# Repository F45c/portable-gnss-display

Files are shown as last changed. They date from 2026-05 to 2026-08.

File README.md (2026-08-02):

# Portable GNSS / GPS Display
### What it is
The Display shows a satellite map of your nearby surroundings with an indicator in the center of the device's location. It not only uses GPS satellites but also the european Galileo, BeiDou and some others.
With the UART connections and USB connectors, you can read the position with a phone or a computer.

### How it works
It uses the ublox neo m9n chip with an active antenna and an Esp32-C3 that extracts the position, calculates the tiles to draw on the screen and draws them together with a position mark on the display.
The tiles are stored on sd card slot in the tft display and are pre-downloaded on set sd card for a small area around my home town.

### Finished Module
I finished the PCB assembly. It was difficult to solder the tiny components and especially the SMD parts. Thankfully, with the help of solder flux and a heat gun, I was able to solder everything on the pcb.
The most annoying component was the USB-C connector because the pins are so tiny and would always bridge multiple together.

I downloaded a few tiles where I live and put them on an sd card. I had to censor the map mostly so I don't leak my address. The example image is below.

It's a very nice device but after all, I still use my phone more often than this.

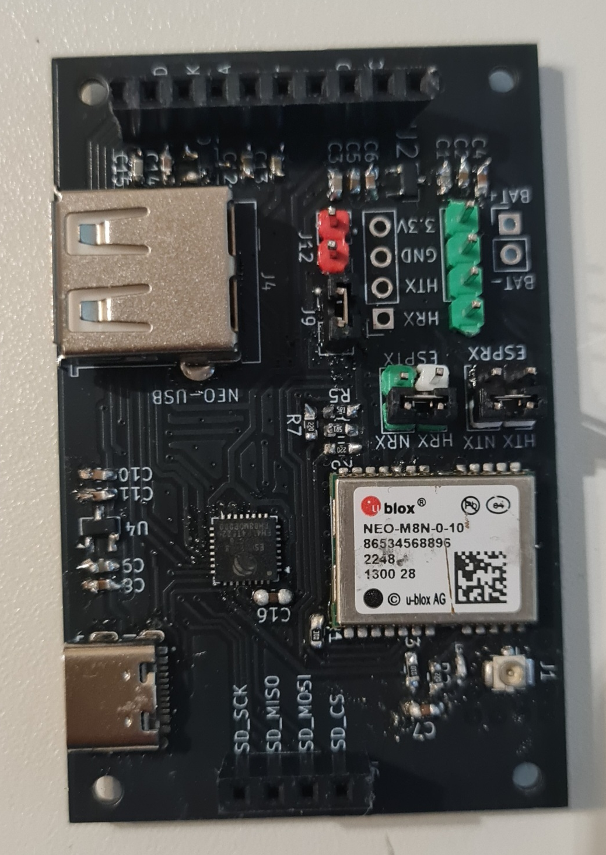
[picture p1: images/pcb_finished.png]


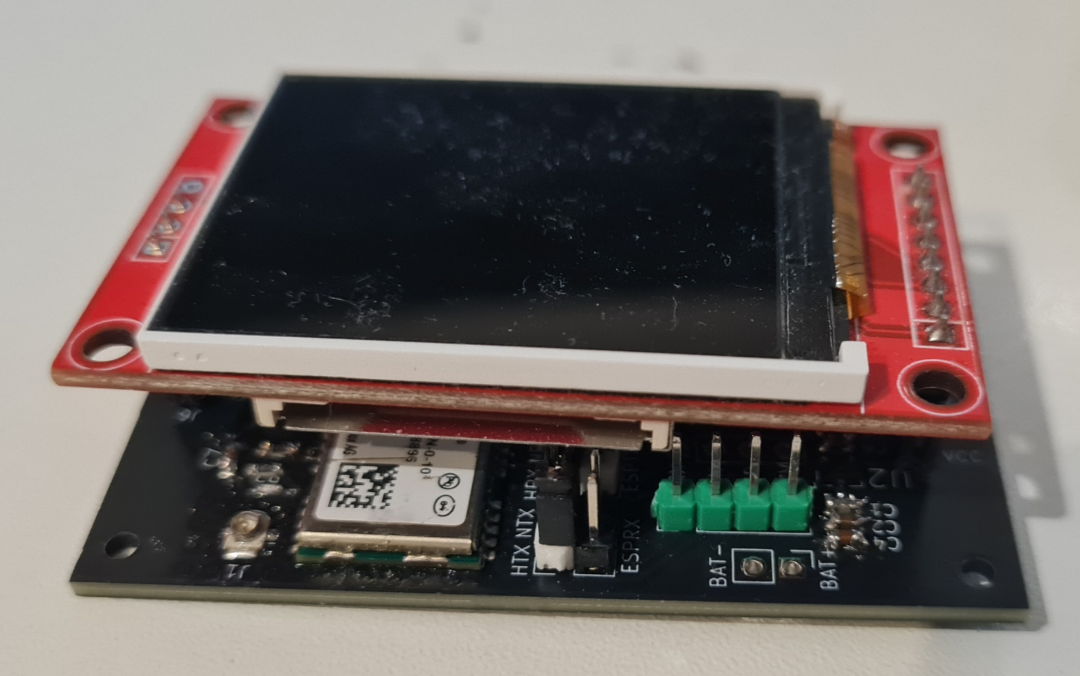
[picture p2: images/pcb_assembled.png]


(Redacted display because it shows my home location)

In the center, on the red + symbol is the gps position and on top is the N for north.

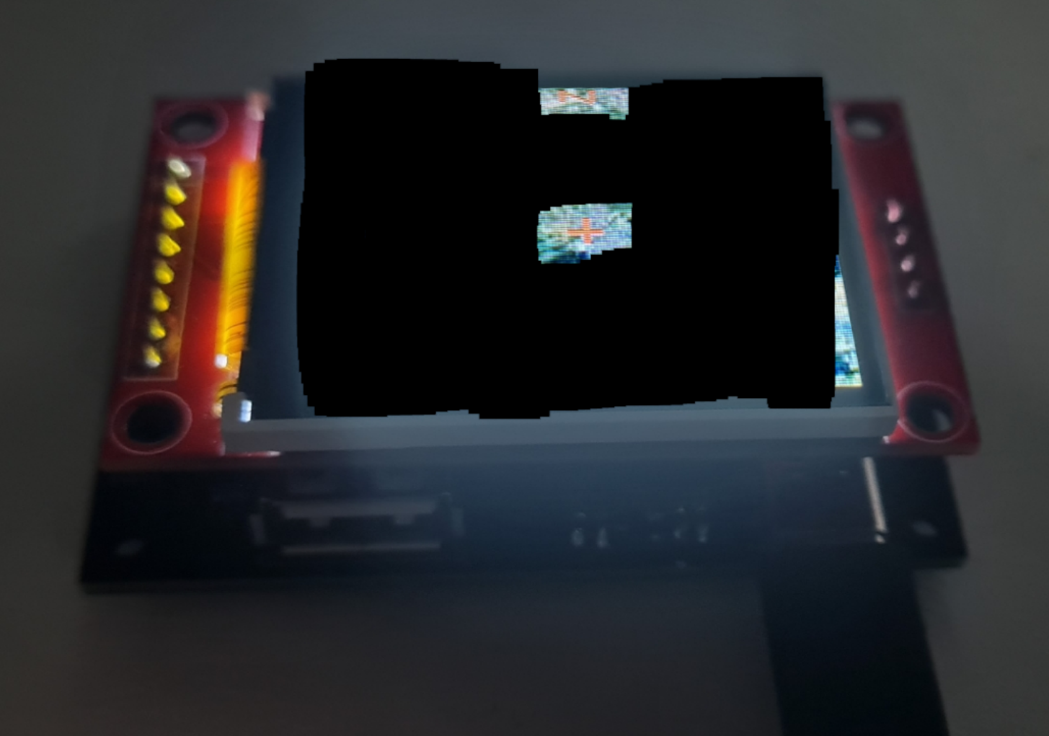
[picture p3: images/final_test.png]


#### Technical Details
> The Neo M9N can be directly connected via USB-A Connector to an external device
>
>The Esp32 and Neo communicate over UART with baud rate 9600
>
>The Esp32 communicates with the display and sd card over SPI
>
>
>With some jumper pins, you can configure which part of the PCB is powered with what source.
>
>The UART pin headers are for using an external uart connection to read the position or communicate with the Esp32.
>This can also be configured using jumper pins

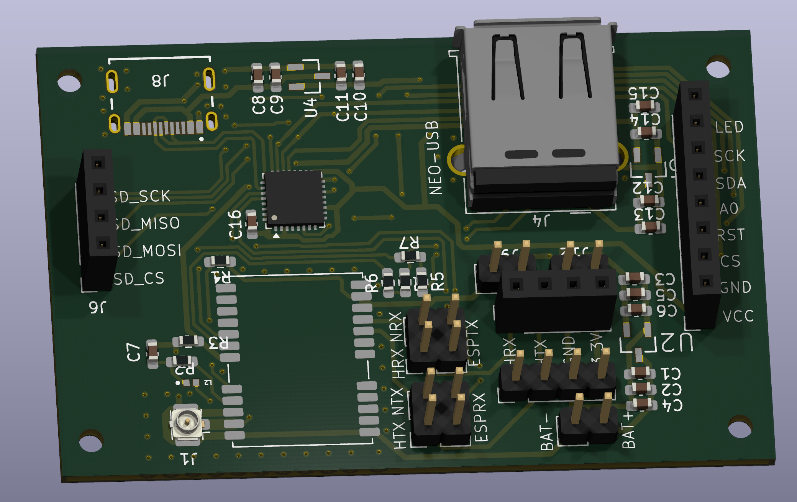
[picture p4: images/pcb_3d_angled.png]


#### Components
> uBlox Neo M9N -> GNSS Receiver
>
> Esp32-C3 -> processor
>
>  1.8 inch TFT Display with SD CARD -> Display
>
> Active Antenna -> better reception
>
> MCP170XT-3302E -> 3.3V Linear Voltage Regulator

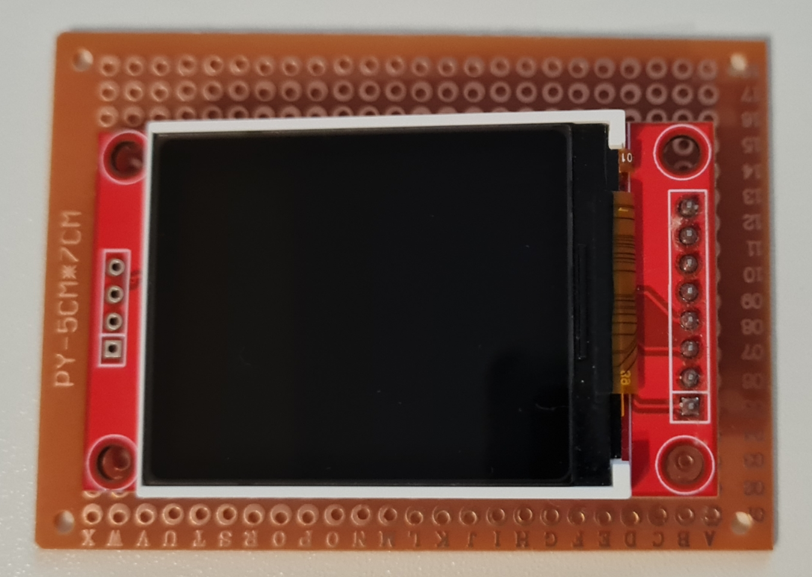
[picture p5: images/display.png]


### Why I made this
I wanted to have a device showing my exact location reliably because google maps sometimes doesn't show my location when my phone has bad cellular reception (even with good gps reception).

I also like satellite maps instead of normal street lines maps to better see what's around me and since the satellite images aren't up to date, you can see how the world changed.

It's kind of an extra gadget that doesn't require a phone to work and, as mentioned, runs reliably all the time, can't be hacked etc.

### Schematic

#### Some mentionable parts
> 27 Ω resistors (22+5.1) between D+/D- lines to Neo for full-speed driver
>
> lots of capacitors around LDOs for stable voltage
>
> important bias T at antenna input for active antennas
>
> Neo VDD_USB needs to be pulled down when not in use
>
> Jumper pin configuring happening on the left
>
> Three power source inputs to choose from (USB-A, USB-C, battery)

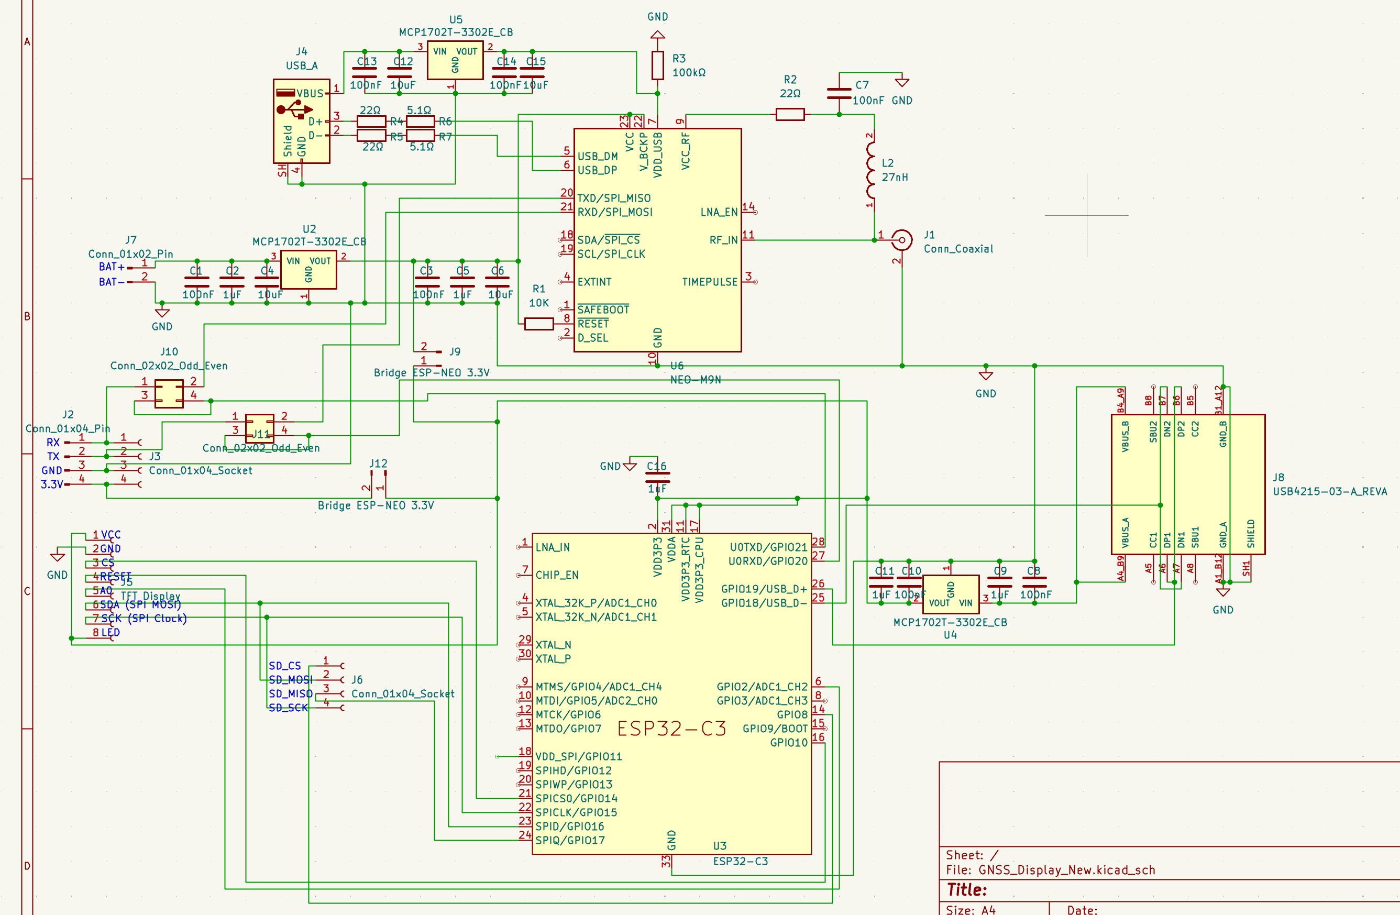
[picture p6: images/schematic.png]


### PCB Design
The first thing to mention is that the 1.8inch display has enough room and isn't blocked by any components. I made sure of that through the entire development process.

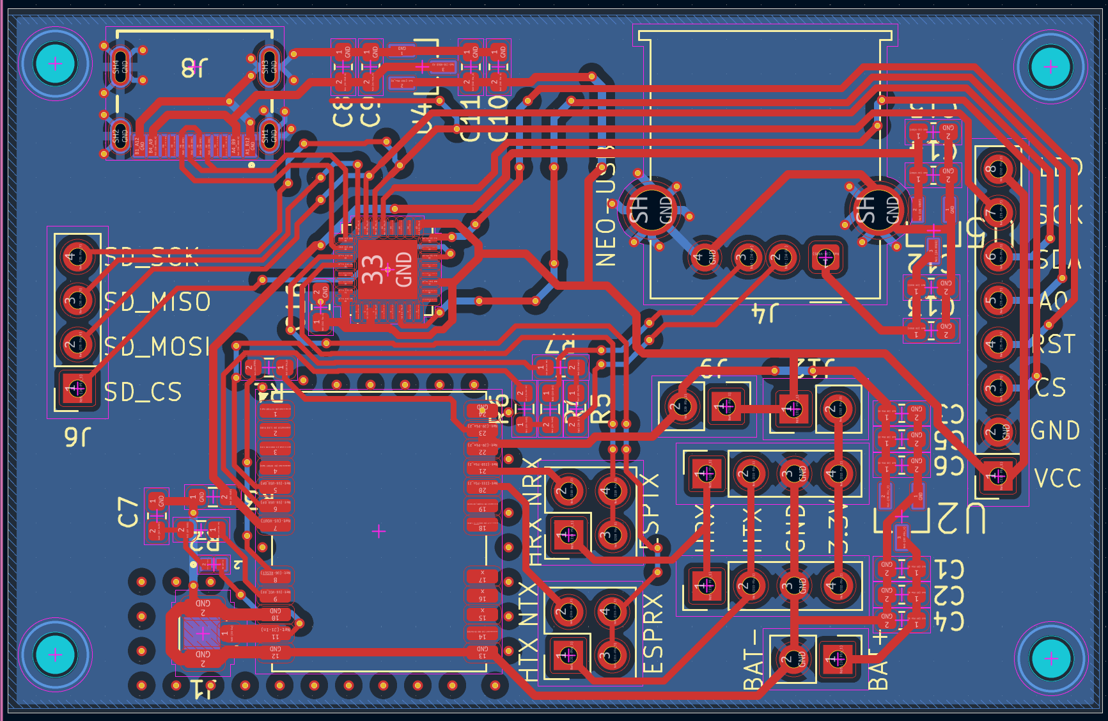
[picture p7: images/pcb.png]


#### Key Aspects of the Design
> minimum track width = 0.3mm, most power traces = 0.5mm
> lots of vias around the Neo and antenna connector shielding from interference
> four mounting holes when I want to screw it onto something
> tried to make it as small as possible
> track from antenna to Neo Pin has 50ohm impedance
> Ground Plane

When routing on the back layer (ground plane), I tried to make short cuts between the tracks so that the ground plane works better and the path of the current is as short as possible.

Here is an example of this where you can see the spacing between the different tracks on the ground plane (blue layer)

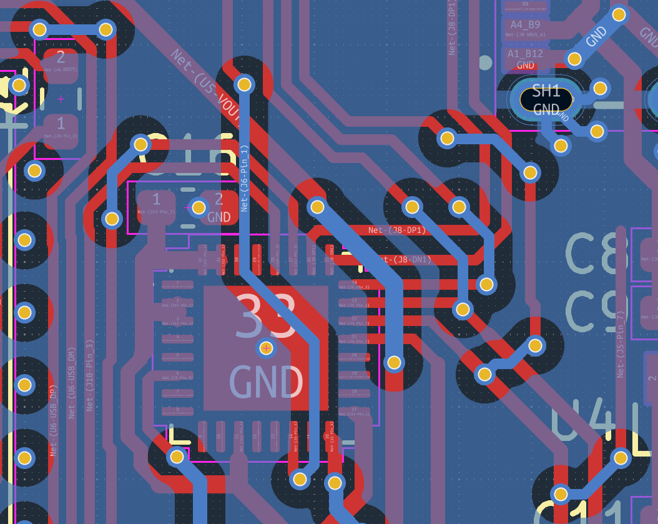
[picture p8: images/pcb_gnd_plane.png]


### BOM

| Name | Purpose | Quantity | Total Cost (USD) | Link | Distributor |
|---|---|---|---|---|---|
| PCB | PCB board | 1 | 5.50 | | JLCPCB |
| Display | 1.8 inch TFT display | 1 | 6.47 | [Link](https://www.amazon.com/Chiffonade-Display-Interface-128x160-Resolution/dp/B0FQJX2SJV/) | Amazon |
| Antenna | GPS Antenna | 1 | 7.99 | [Link](https://www.amazon.com/28dB-High-Active-Antenna-Built/dp/B0C3H6BKHC) | Amazon |
| PCBA | PCB Assembly Parts | 1 | 33.27 | | |

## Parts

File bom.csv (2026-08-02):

Name | Purpose | Quantity | Total Cost (USD) | Link | Distributor
PCB | PCB board | 1 | 5.5 |  | JLCPCB
Display | 1.8 inch TFT display | 1 | 6.47 | https://www.amazon.com/Chiffonade-Display-Interface-128x160-Resolution/dp/B0FQJX2SJV/ | Amazon
Antenna | GPS Antenna | 1 | 7.99 | https://www.amazon.com/28dB-High-Active-Antenna-Built/dp/B0C3H6BKHC | Amazon
PCBA | PCB Assembly Parts | 1 | 33.27

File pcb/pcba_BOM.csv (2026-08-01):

Reference | Qty | Value | DNP | Exclude from BOM | Exclude from Board | Footprint | Datasheet
C1,C3,C7,C8,C10,C13,C14 | 7 | 100nF |  |  |  | Capacitor_SMD:C_0603_1608Metric_Pad1.08x0.95mm_HandSolder
C2,C5,C9,C11,C16 | 5 | 1uF |  |  |  | Capacitor_SMD:C_0603_1608Metric_Pad1.08x0.95mm_HandSolder
C4,C6,C12,C15 | 4 | 10uF |  |  |  | Capacitor_SMD:C_0603_1608Metric_Pad1.08x0.95mm_HandSolder
J1 | 1 | Conn_Coaxial |  |  |  | Connector_Coaxial:U.FL_Hirose_U.FL-R-SMT-1_Vertical
J2 | 1 | Conn_01x04_Pin |  |  |  | Connector_PinHeader_2.54mm:PinHeader_1x04_P2.54mm_Vertical
J3,J6 | 2 | Conn_01x04_Socket |  |  |  | Connector_PinSocket_2.54mm:PinSocket_1x04_P2.54mm_Vertical
J4 | 1 | USB_A |  |  |  | Connector_USB:USB_A_Molex_67643_Horizontal
J5 | 1 | TFT Display |  |  |  | Connector_PinSocket_2.54mm:PinSocket_1x08_P2.54mm_Vertical
J7 | 1 | Conn_01x02_Pin |  |  |  | Connector_PinHeader_2.54mm:PinHeader_1x02_P2.54mm_Vertical
J8 | 1 | USB4215-03-A_REVA |  |  |  | USB4215-03-A_REVA:GCT_USB4215-03-A_REVA
J9,J12 | 2 | Bridge ESP-NEO 3.3V |  |  |  | Connector_PinHeader_2.54mm:PinHeader_1x02_P2.54mm_Vertical
J10,J11 | 2 | Conn_02x02_Odd_Even |  |  |  | Connector_PinHeader_2.54mm:PinHeader_2x02_P2.54mm_Vertical
L2 | 1 | 27nH |  |  |  | LQG15HS27NJ02D:INDC1005X55N
R1 | 1 | 10K |  |  |  | Resistor_SMD:R_0603_1608Metric_Pad0.98x0.95mm_HandSolder
R2,R4,R5 | 3 | 22Ω |  |  |  | Resistor_SMD:R_0603_1608Metric_Pad0.98x0.95mm_HandSolder
R3 | 1 | 100kΩ |  |  |  | Resistor_SMD:R_0603_1608Metric_Pad0.98x0.95mm_HandSolder
R6,R7 | 2 | 5.1Ω |  |  |  | Resistor_SMD:R_0603_1608Metric_Pad0.98x0.95mm_HandSolder
U2,U4,U5 | 3 | MCP1702T-3302E_CB |  |  |  | MCP1702T-3302E_CB:SOT95P255X145-3N
U3 | 1 | ESP32-C3 |  |  |  | Package_DFN_QFN:QFN-32-1EP_5x5mm_P0.5mm_EP3.45x3.45mm | https://www.espressif.com/sites/default/files/documentation/esp32-c3_datasheet_en.pdf
U6 | 1 | NEO-M9N |  |  |  | RF_GPS:ublox_NEO | https://www.u-blox.com/sites/default/files/NEO-M9N-00B_DataSheet_UBX-19014285.pdf

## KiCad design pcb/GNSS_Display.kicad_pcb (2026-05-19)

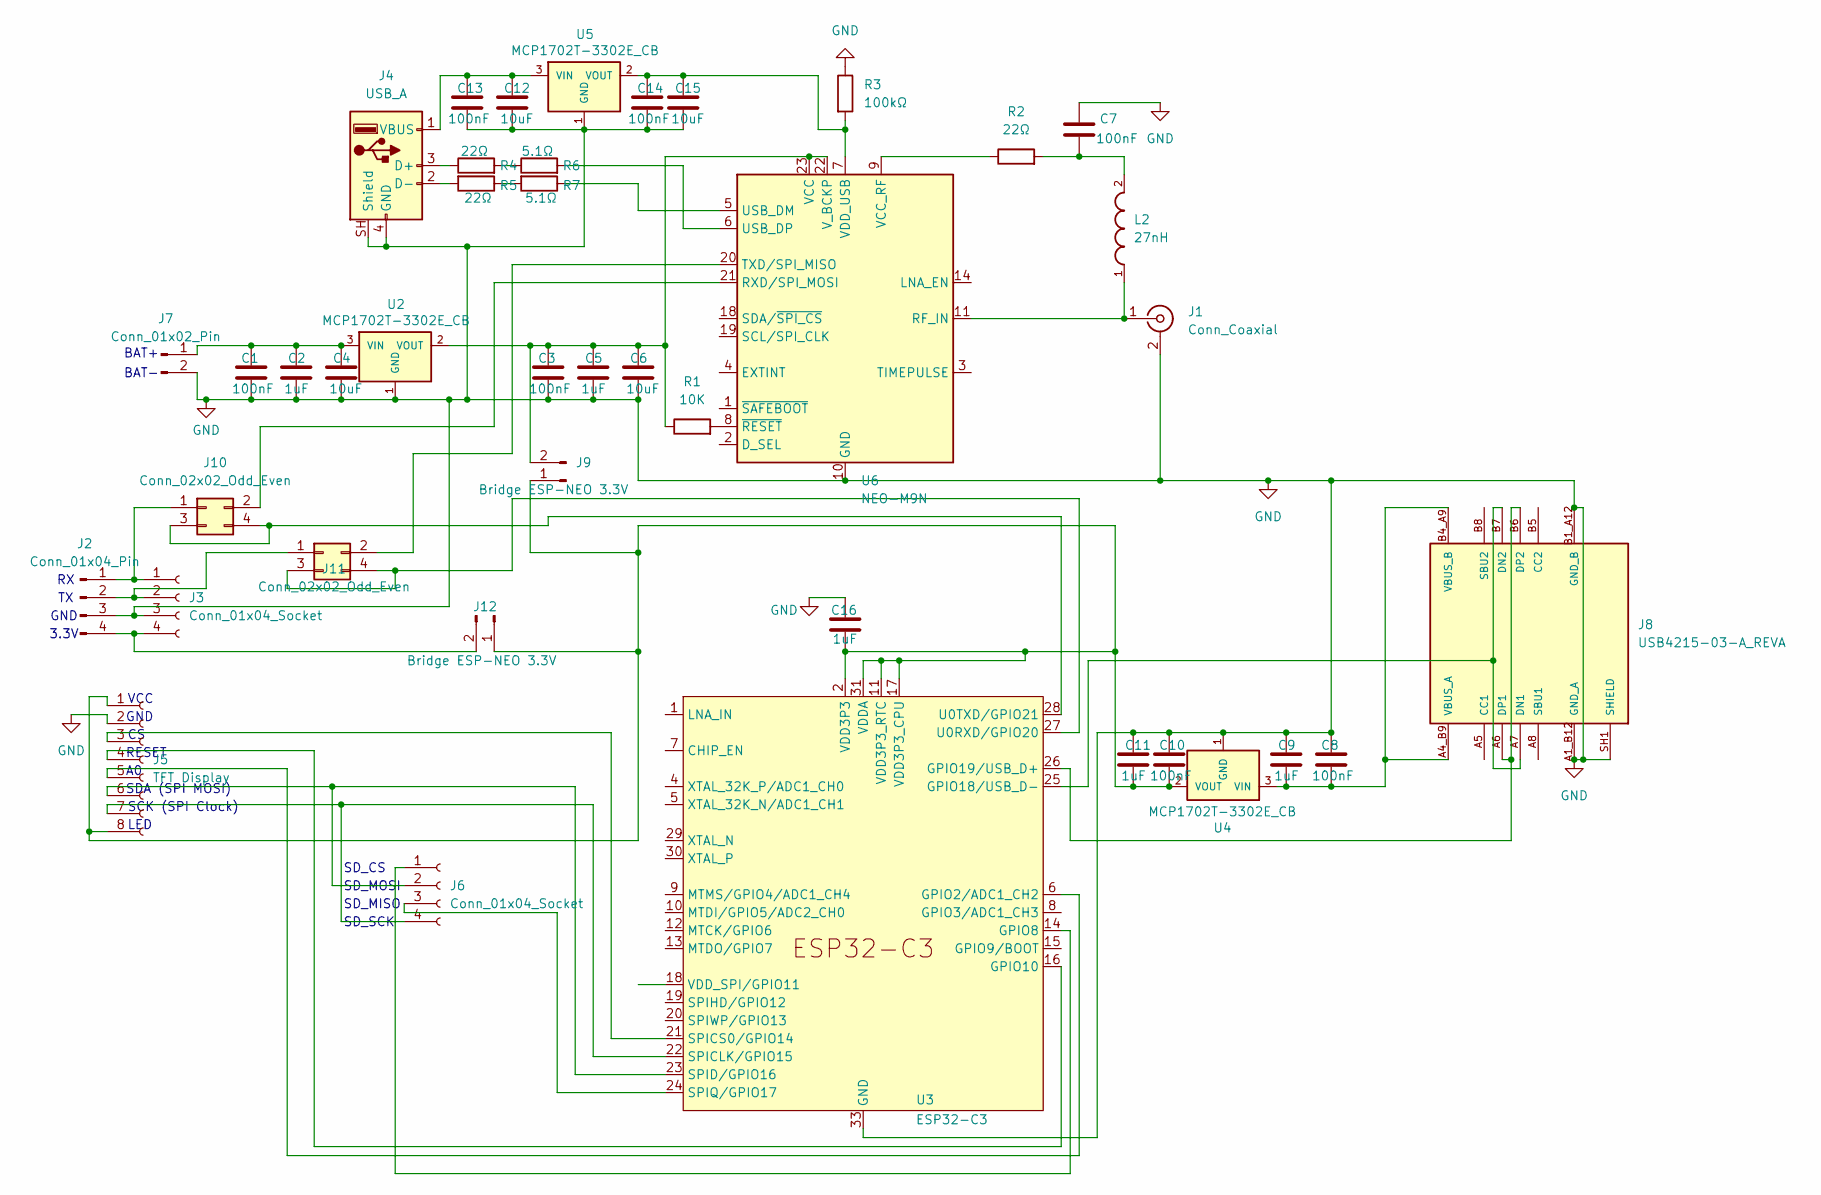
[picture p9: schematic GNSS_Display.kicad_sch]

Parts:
C1, C3, C7, C8, C10, C13, C14: 100nF; C_0603_1608Metric_Pad1.08x0.95mm_HandSolder
C2, C5, C9, C11, C16: 1uF; C_0603_1608Metric_Pad1.08x0.95mm_HandSolder
C4, C6, C12, C15: 10uF; C_0603_1608Metric_Pad1.08x0.95mm_HandSolder
J1: Conn_Coaxial; U.FL_Hirose_U.FL-R-SMT-1_Vertical
J2: Conn_01x04_Pin; PinHeader_1x04_P2.54mm_Vertical
J3, J6: Conn_01x04_Socket; PinSocket_1x04_P2.54mm_Vertical
J4: USB_A; USB_A_Molex_67643_Horizontal
J5: TFT Display; PinSocket_1x08_P2.54mm_Vertical
J7: Conn_01x02_Pin; PinHeader_1x02_P2.54mm_Vertical
J8: USB4215-03-A_REVA; GCT_USB4215-03-A_REVA; PARTREV A
J9, J12: Bridge ESP-NEO 3.3V; PinHeader_1x02_P2.54mm_Vertical
J10, J11: Conn_02x02_Odd_Even; PinHeader_2x02_P2.54mm_Vertical
L2: 27nH; INDC1005X55N
R1: 10K; R_0603_1608Metric_Pad0.98x0.95mm_HandSolder
R2, R4, R5: 22Ω; R_0603_1608Metric_Pad0.98x0.95mm_HandSolder
R3: 100kΩ; R_0603_1608Metric_Pad0.98x0.95mm_HandSolder
R6, R7: 5.1Ω; R_0603_1608Metric_Pad0.98x0.95mm_HandSolder
U2, U4, U5: MCP1702T-3302E_CB; SOT95P255X145-3N; MPN MCP1702T-3302E/CB
U3: ESP32-C3; QFN-32-1EP_5x5mm_P0.5mm_EP3.45x3.45mm
U6: NEO-M9N; ublox_NEO

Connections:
GND: C1.2, C2.2, C3.2, C4.2, C5.2, C6.2, C7.1, C8.1, C9.1, C10.1, C11.1, C12.2, C13.2, C14.2, C15.2, C16.2, J1.2 (Ext), J2.3, J3.3, J4.4 (GND), J4.SH (Shield), J5.2, J7.2, J8.A1_B12 (GND_A), J8.B1_A12 (GND_B), J8.SH1 (SHIELD), J8.SH2 (SHIELD), J8.SH3 (SHIELD), J8.SH4 (SHIELD), R3.1, U2.1 (GND), U3.33 (GND), U4.1 (GND), U5.1 (GND), U6.10 (GND), U6.12 (GND), U6.13 (GND), U6.24 (GND)
unnamed: C7.2, L2.2, R2.2
unnamed: J1.1 (In), L2.1, U6.11 (RF_IN)
unnamed: J4.3 (D+), R4.1
unnamed: J4.2 (D-), R5.2
unnamed: C12.1, C13.1, J4.1 (VBUS), U5.3 (VIN)
unnamed: J5.3, U3.21 (SPICS0/GPIO14)
unnamed: J5.4, U3.16 (GPIO10)
unnamed: J5.5, U3.6 (GPIO2/ADC1_CH2)
unnamed: J5.6, J6.2, U3.23 (SPID/GPIO16)
unnamed: J5.7, J6.4, U3.22 (SPICLK/GPIO15)
unnamed: J6.1, U3.14 (GPIO8)
unnamed: J6.3, U3.24 (SPIQ/GPIO17)
unnamed: C1.1, C2.1, C4.1, J7.1, U2.3 (VIN)
unnamed: J8.A7 (DN1), J8.B7 (DN2), U3.25 (GPIO18/USB_D-)
unnamed: J8.A6 (DP1), J8.B6 (DP2), U3.26 (GPIO19/USB_D+)
unnamed: C8.2, C9.2, J8.A4_B9 (VBUS_A), J8.B4_A9 (VBUS_B), U4.3 (VIN)
unnamed: C3.1, C5.1, C6.1, J9.2, R1.1, U2.2 (VOUT), U6.22 (V_BCKP), U6.23 (VCC)
unnamed: J2.1, J3.1, J10.1
unnamed: J10.2, U6.21 (RXD/SPI_MOSI)
unnamed: J10.3, J10.4, U3.28 (U0TXD/GPIO21)
unnamed: J2.2, J3.2, J11.1
unnamed: J11.2, U6.20 (TXD/SPI_MISO)
unnamed: J11.3, J11.4, U3.27 (U0RXD/GPIO20)
unnamed: C10.2, C11.2, C16.1, J5.1, J5.8, J9.1, J12.1, U3.2 (VDD3P3), U3.3 (VDD3P3), U3.11 (VDD3P3_RTC), U3.17 (VDD3P3_CPU), U3.31 (VDDA), U3.32 (VDDA), U4.2 (VOUT)
unnamed: J2.4, J3.4, J12.2
unnamed: R4.2, R6.1
unnamed: R5.1, R7.2
unnamed: C14.1, C15.1, R3.2, U5.2 (VOUT), U6.7 (VDD_USB)
unnamed: R7.1, U6.5 (USB_DM)
unnamed: R6.2, U6.6 (USB_DP)
unnamed: R2.1, U6.9 (VCC_RF)
unnamed: R1.2, U6.8 (~RESET)

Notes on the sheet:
SDA (SPI MOSI)
GND
SD_SCK
BAT+
SD_MISO
RESET
SD_MOSI
VCC
3.3V
SCK (SPI Clock)
BAT-
LED
SD_CS

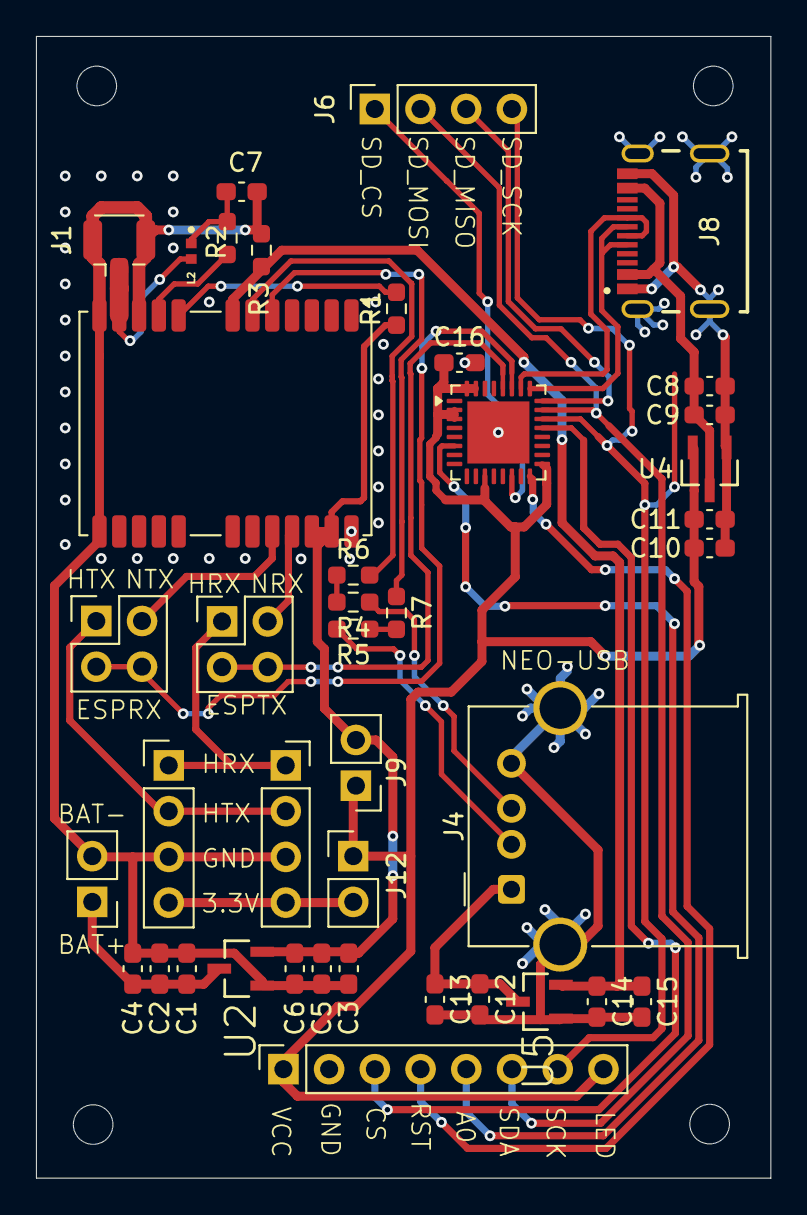
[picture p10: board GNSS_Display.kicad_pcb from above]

Board: 2 copper layers, 40.8 x 63.4 mm, 41 parts (0 on the bottom side), 33 nets.

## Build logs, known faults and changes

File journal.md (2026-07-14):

# Soldering USB Connectors

_Time spent: 1h_

As my components arrived, I started soldering the big parts first so that I don't blow the tiny capacitors away with the heat gun if I were to do it the other way around.

Firstly, I tried soldering the USB-C connector with a soldering iron which got really messy because of the small pins of the connector. So I watched some youtube tutorials on how to solder smd components correctly where I learned some new techniques. In the end, I used solder paste and a heat gun and had to fix it a couple times until it looked good und a lens.

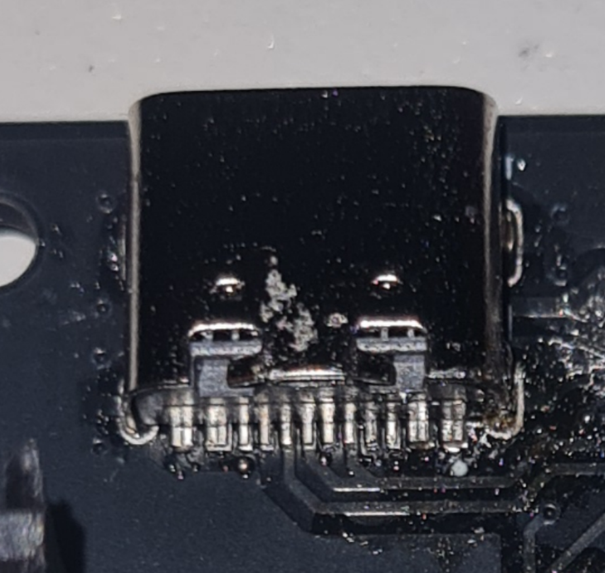
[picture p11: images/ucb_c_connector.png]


For the USB-A connector, I had to use a lot of solder paste to fill the shielding pin holes but except that, this component was easy to solder.

# Finishing PCB Assembly

_Time spent: 1.5h_

The next big part was the NEO M8N to solder to the PCB. I used the heat gun with solder paste and it took a few tries to get every pin connected. Next were the pin headers for UART and power configuration and the pin sockets for the display. For these components, it worked well to solder them with the soldering iron. The resistors and capacitors were more difficult because the iron would sometimes hold on to them and pull them off again. The linear voltage regulators are also SMD components but their pins are much easier to solder. For the U.Fl (antenna) connector, I again used an hot air gun requiring only a little retries.

At the end, I connected power to the board and measured some places and the voltage flew correctly.



# Testing the final build

_Time spent: 0.33h_

I downloaded a few tiles where I live and put them on the sd card. I used the google satellite images API with zoom level 15. After like 15min in line of sight to the sky, the neo m8n finished downloading the current satellite positions and got the first fix.

Below is an example image of the map with my position but I had to censor most of the map so that I don't leak my address. The tiles are centered on my position being displayed by the + symbol. On top, there is the N for north direction of the map.



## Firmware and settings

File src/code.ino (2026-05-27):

#include <SD_MMC.h>
#include <Adafruit_ST7735.h>
#include <TinyGPS++.h>

#define TFT_CS  14
#define TFT_DC   2
#define TFT_RST  10
#define ZOOM    20

Adafruit_ST7735 tft(TFT_CS, TFT_DC, TFT_RST);
TinyGPSPlus gps;
uint64_t tileX, tileY;

void gpsToTile(float lat, float lon) { // tile calculation for the tile API I used
  uint64_t n = 1ULL << ZOOM; // bit shifting for power of
  tileX = (lon + 180.0) / 360.0 * n;
  double r   = lat * PI / 180.0;
  tileY = (1.0 - log(tan(r) + 1.0 / cos(r)) / PI) / 2.0 * n;
}

void setup() {
  Serial2.begin(9600, SERIAL_8N1, 20, 21);
  tft.initR(INITR_BLACKTAB);
  tft.fillScreen(ST77XX_BLACK);
  SD_MMC.begin("/sdcard", true);
}

void loop() {
  while (Serial2.available()) {
    gps.encode(Serial2.read());
  }

  if (gps.location.isUpdated()) {
    gpsToTile(gps.location.lat(), gps.location.lng());

    int width = tft.width();
    int height = tft.height();

    char path[48];
    // I store the bitmap as 16 bit (RGB565) without header, just raw pixels
    snprintf(path, sizeof(path), "/tiles_20/tile_%llu_%llu.bin", tileX, tileY); // %llu for long long (uint64_t)
    File f = SD_MMC.open(path);
    if (!f) return;

    const uint64_t size = 256 * 128 * 2;
    uint16_t pixels[size]; // don't know how much ram it has, so drawing first half
    f.seek(size);
    f.read((uint8_t*) &pixels, size);

    tft.drawRGBBitmap(0, 0, (uint16_t*) &pixels, 256, 128);

    f.seek(size);
    f.read((uint8_t*) &pixels, size); // read second half

    tft.drawRGBBitmap(0, 0, (uint16_t*) &pixels, 256, 128); // draw second half
    free(pixels);

    f.close();
  }
}

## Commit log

2026-05-19 added KiCAD files and gerbers.zip
    [GNSS_Display.kicad_pcb, GNSS_Display.kicad_sch]
2026-05-19 added pcb image
2026-05-19 added schematic image
2026-05-20 added example image of gnd plane routing
2026-05-20 rotated pcb image
2026-05-20 added pcb to readme
2026-05-27 added firmware for the esp32c3
2026-05-27 added stl 3d model
2026-06-12 added bom.csv
    [bom.csv]
2026-06-12 added bom to readme
2026-07-14 added usb connector image
2026-08-01 added pcba bom
    [pcba_BOM.csv]
2026-08-01 fixed bom
    [bom.csv]
2026-08-01 fixed bom in readme
2026-08-02 moved pcba bom into pcb folder
    [pcba_BOM.csv]
2026-08-02 changed bom.csv
    [bom.csv]
2026-08-02 added pcba to bom
    [bom.csv]
2026-08-02 added pcba to bom in readme
